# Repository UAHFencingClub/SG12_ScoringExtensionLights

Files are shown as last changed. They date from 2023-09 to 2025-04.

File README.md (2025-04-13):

# SG12_ScoringExtensionLights

A module for the [SG12 fencing scoring machine](https://www.blue-gauntlet.com/SG12-ST-MACHINE-w-score-and-time-and-remote_p_3799.html) that allows for 12V LED strips to be used as extension lights.

You can view the mirror on [CADLAB.io](https://cadlab.io/project/27194/main/files) if you want to see the schematic. < Needs to be updated, not sure why mirroring is not working.

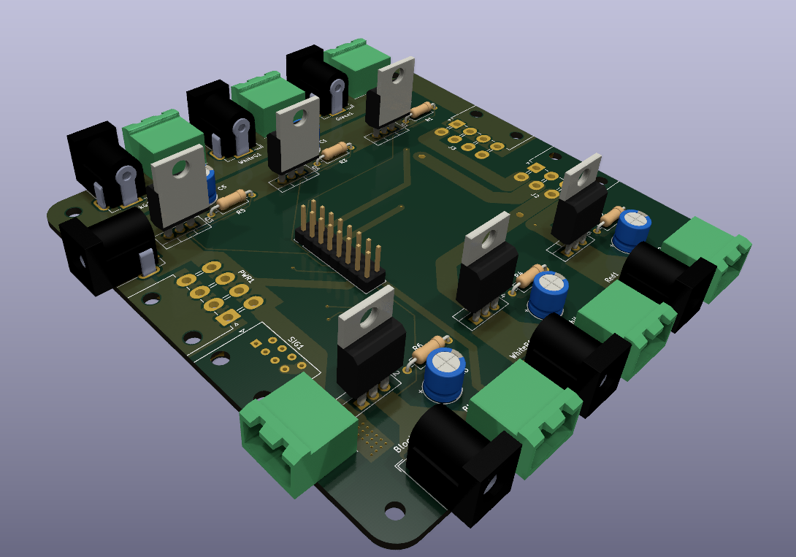
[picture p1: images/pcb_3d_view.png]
Image of 3D PCB Rendering


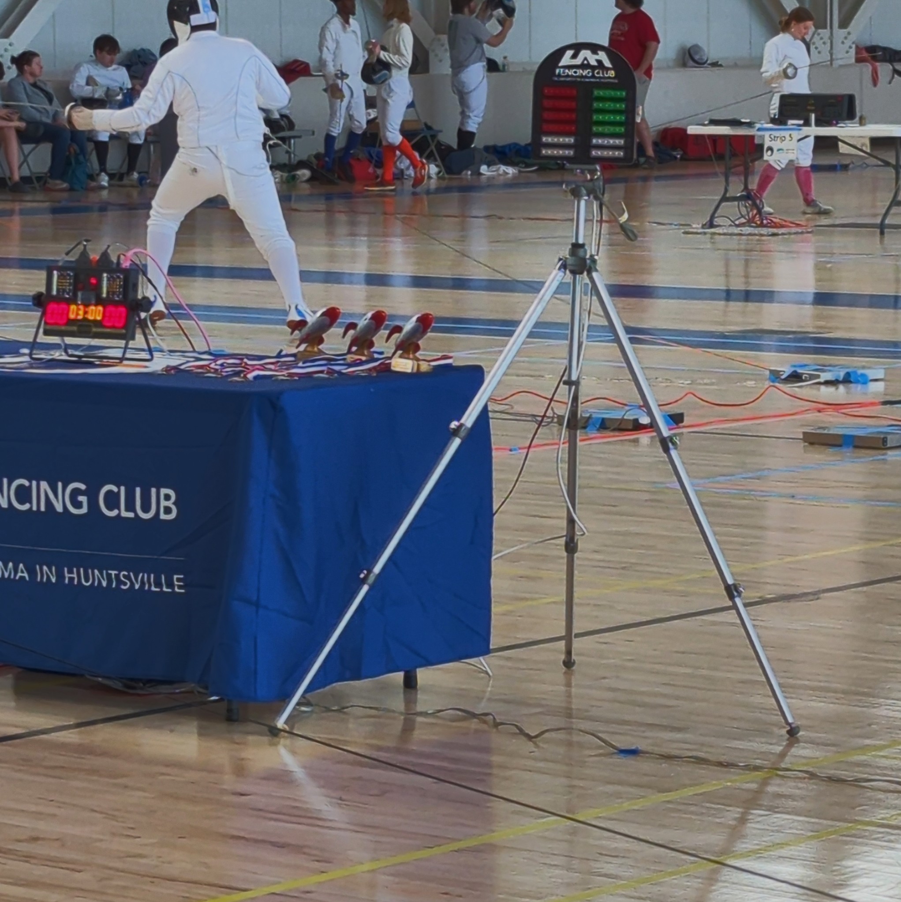
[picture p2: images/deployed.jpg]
Deployed Extension Lights


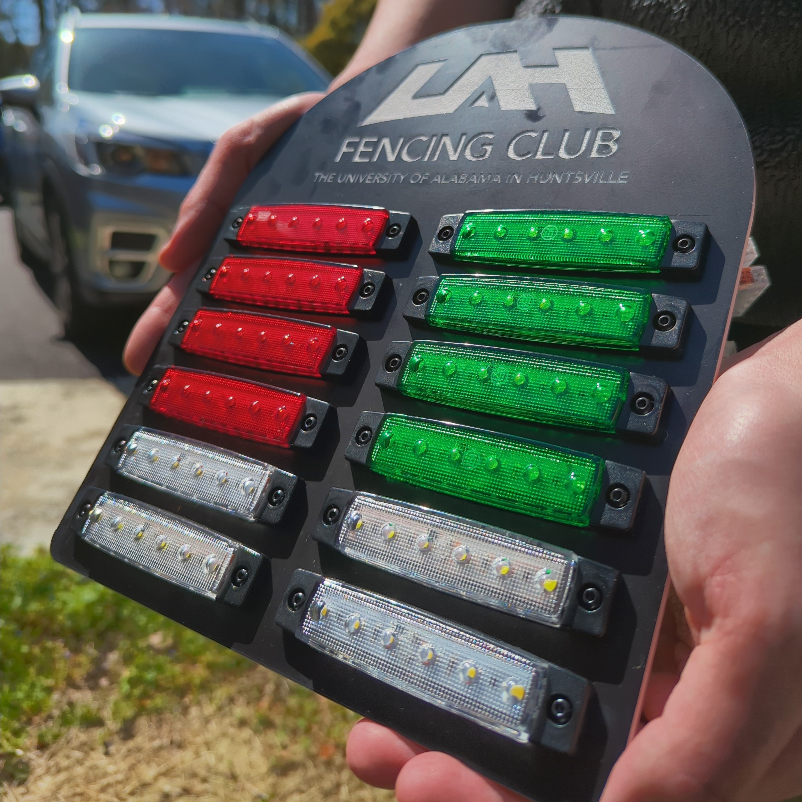
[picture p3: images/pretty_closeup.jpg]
Closeup


# Wiring Diagram

Annocations and a wiring diagram can be found [here](Wiring.md)

# Parts (Haphazard)

Most things I got off amazon. I have not gotten all the connectors since not all are actually required. It depends on what you need. Look at the schematic to find out.

- IRF4905 MOSFET (Though probably most P Channel MOSFETs will do)
- Some sort of RJ45 (Ethernet) Connector (Don't get the ones with built in magnetics, those are usually a bit larger and are only for actual ethernet applications.
- Whatever 10k resistors you can find, the value really does not matter I would suggest something between 1k and 100k
- Some sort of barrel jack connector (Inner pin diameter of 2.1mm is more common than ones with 2.5mm inner pin diameter)
- PhoenixContact MSTBA 2,5 2-G-5,08 1x02 P5.08mm Horizontal
- Molex Mini-Fit Jr 5569 2x04 P4.20mm Horizontal
- Standard 2.54mm pin header

# Get PCBs

**Disclaimer: If ordering through their site, PCBWay will "donate 10% PCB and PCB assembly cost to" [me](https://github.com/QuantumEF)**

<a href="https://www.pcbway.com/project/shareproject/SG12_ScoringExtensionLights_36ba9fa8.html">PCB from PCBWay</a>

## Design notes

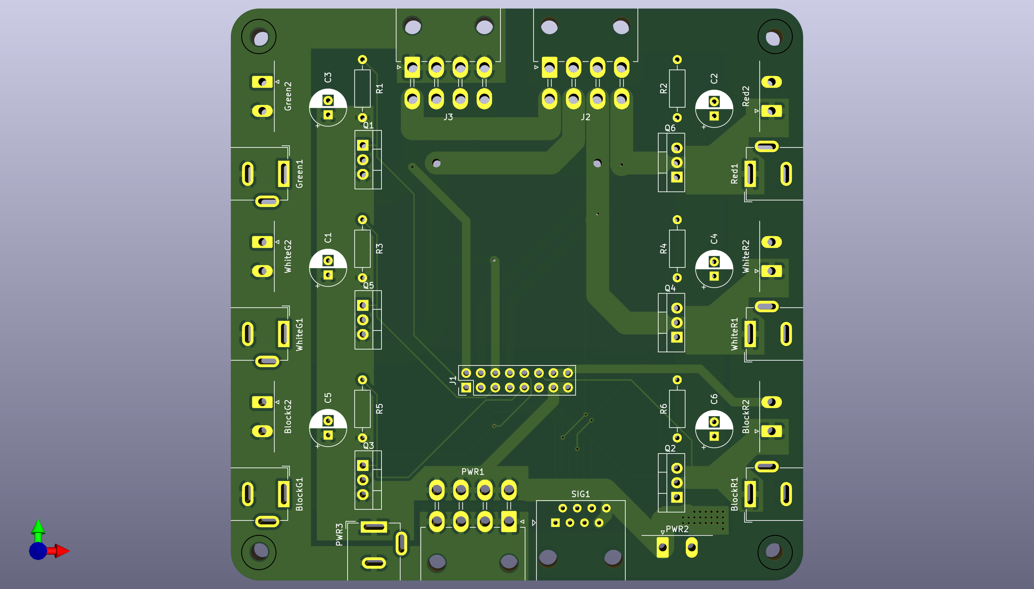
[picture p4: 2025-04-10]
images/pcb_3d_view_birdseye.png

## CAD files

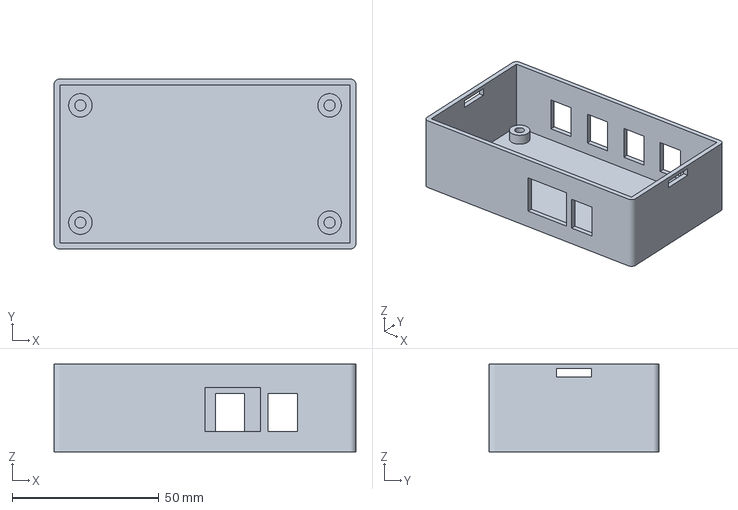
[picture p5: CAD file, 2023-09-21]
3dmodels/Case-CaseFull.3mf
103.0 x 58.0 x 30.0 mm

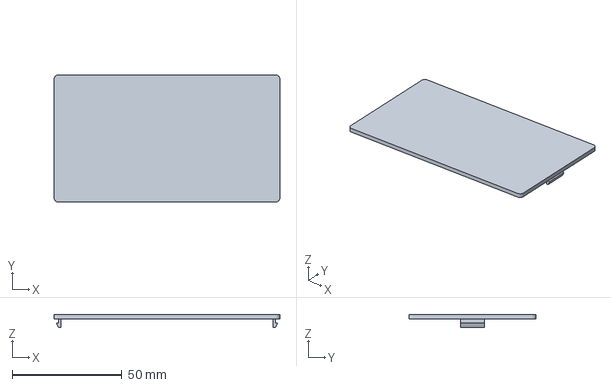
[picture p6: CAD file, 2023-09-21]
3dmodels/Case-LidFull.3mf
103.0 x 58.0 x 6.00 mm

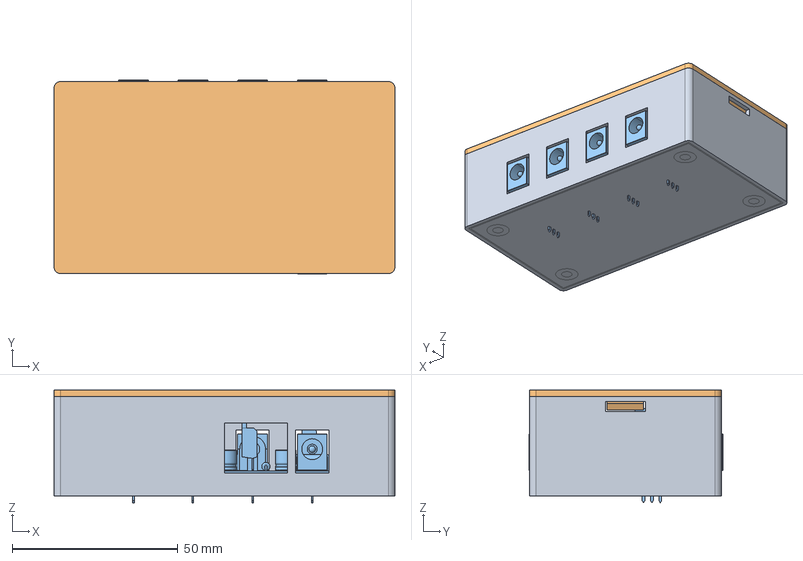
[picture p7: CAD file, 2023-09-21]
3dmodels/Case.FCStd
103.0 x 58.6 x 34.1 mm
CaseFull
LidFull
SG12_Scoring_Extension_Breakout

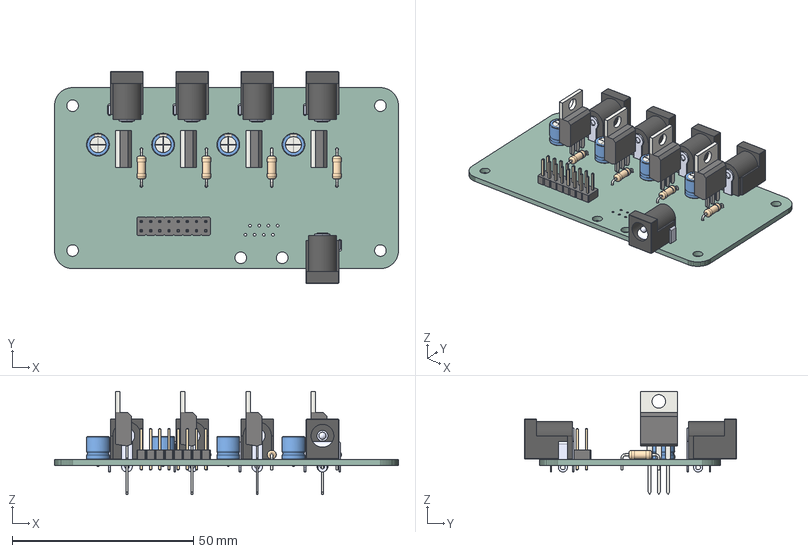
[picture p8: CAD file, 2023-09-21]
3dmodels/SG12_Scoring_Extension_Breakout.step
95.0 x 58.5 x 28.5 mm
SG12_Scoring_Extension_Breakout PCB

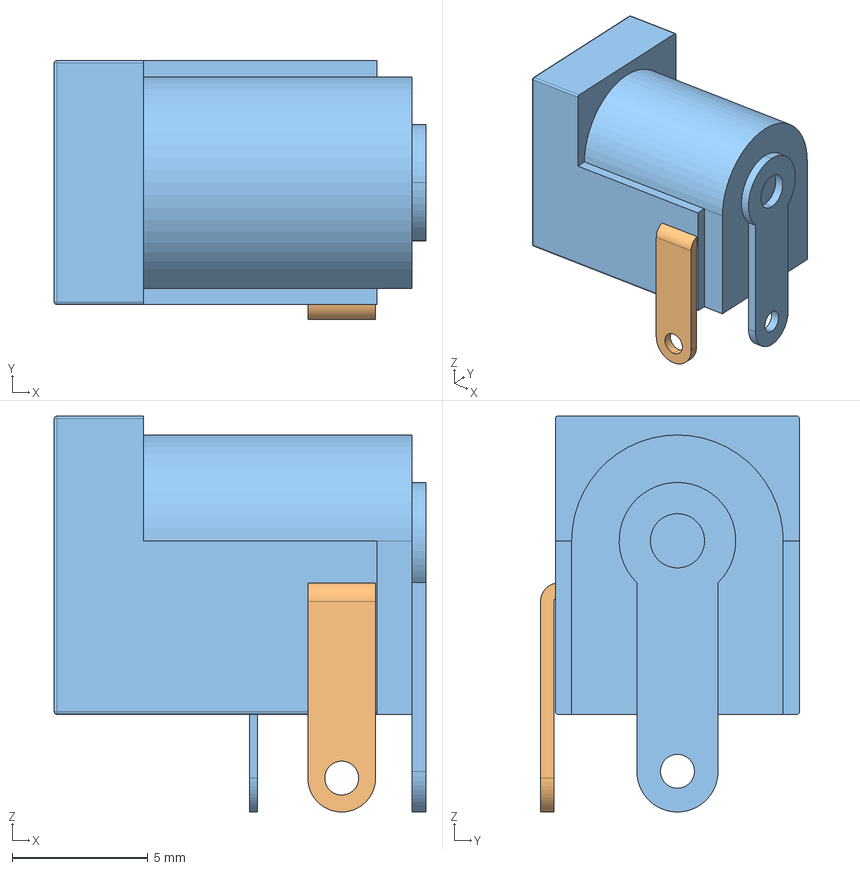
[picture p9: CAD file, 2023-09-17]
3dmodels/Sparkfun_BarrelJack_adaptation.FCStd
13.7 x 9.55 x 14.6 mm

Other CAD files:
3dmodels/Sparkfun_BarrelJack_119.STEP
3dmodels/Sparkfun_BarrelJack_119-adaptation.STEP
3dmodels/Case-CaseFull.stl
3dmodels/Case-LidFull.stl

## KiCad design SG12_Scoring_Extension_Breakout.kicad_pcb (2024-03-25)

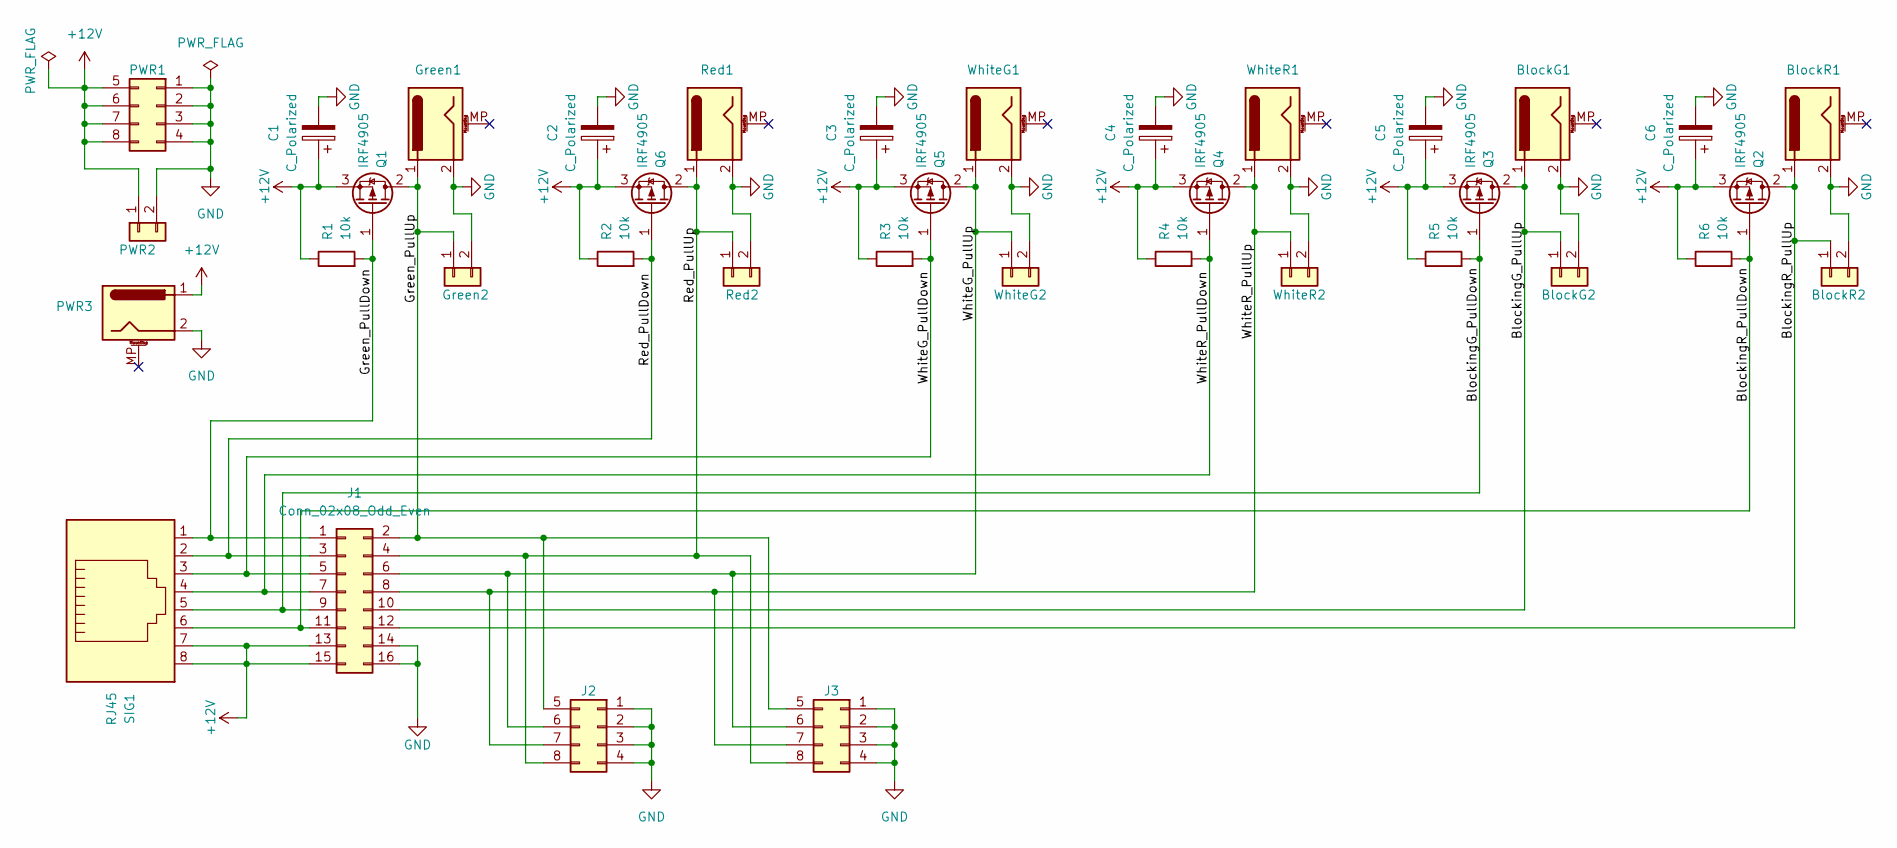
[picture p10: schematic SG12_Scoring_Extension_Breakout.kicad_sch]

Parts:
BlockG1: Barrel_Jack_MountingPin; BarrelJack_GCT_DCJ200-10-A_Horizontal
BlockG2: Conn_01x02; PhoenixContact_MSTBA_2,5_2-G-5,08_1x02_P5.08mm_Horizontal
BlockR1: Barrel_Jack_MountingPin; BarrelJack_GCT_DCJ200-10-A_Horizontal
BlockR2: Conn_01x02; PhoenixContact_MSTBA_2,5_2-G-5,08_1x02_P5.08mm_Horizontal
C1, C2, C3, C4, C5, C6: C_Polarized; CP_Radial_D6.3mm_P2.50mm
Green1: Barrel_Jack_MountingPin; BarrelJack_GCT_DCJ200-10-A_Horizontal
Green2: Conn_01x02; PhoenixContact_MSTBA_2,5_2-G-5,08_1x02_P5.08mm_Horizontal
J1: Conn_02x08_Odd_Even; PinHeader_2x08_P2.54mm_Vertical
J2, J3: Conn_02x04_Top_Bottom; Molex_Mini-Fit_Jr_5569-08A2_2x04_P4.20mm_Horizontal
PWR1: Conn_02x04_Top_Bottom; Molex_Mini-Fit_Jr_5569-08A2_2x04_P4.20mm_Horizontal
PWR2: Conn_01x02; PhoenixContact_MSTBA_2,5_2-G-5,08_1x02_P5.08mm_Horizontal
PWR3: Barrel_Jack_MountingPin; BarrelJack_GCT_DCJ200-10-A_Horizontal
Q1, Q2, Q3, Q4, Q5, Q6: IRF4905; TO-220-3_Vertical
R1, R2, R3, R4, R5, R6: 10k; R_Axial_DIN0207_L6.3mm_D2.5mm_P10.16mm_Horizontal
Red1: Barrel_Jack_MountingPin; BarrelJack_GCT_DCJ200-10-A_Horizontal
Red2: Conn_01x02; PhoenixContact_MSTBA_2,5_2-G-5,08_1x02_P5.08mm_Horizontal
SIG1: RJ45; RJ45_Amphenol_54602-x08_Horizontal
WhiteG1: Barrel_Jack_MountingPin; BarrelJack_GCT_DCJ200-10-A_Horizontal
WhiteG2: Conn_01x02; PhoenixContact_MSTBA_2,5_2-G-5,08_1x02_P5.08mm_Horizontal
WhiteR1: Barrel_Jack_MountingPin; BarrelJack_GCT_DCJ200-10-A_Horizontal
WhiteR2: Conn_01x02; PhoenixContact_MSTBA_2,5_2-G-5,08_1x02_P5.08mm_Horizontal

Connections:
+12V: C1.1, C2.1, C3.1, C4.1, C5.1, C6.1, J1.13, J1.15, PWR1.5, PWR1.6, PWR1.7, PWR1.8, PWR2.1, PWR3.1, Q1.3 (S), Q2.3 (S), Q3.3 (S), Q4.3 (S), Q5.3 (S), Q6.3 (S), R1.1, R2.1, R3.1, R4.1, R5.1, R6.1, SIG1.7, SIG1.8
/BlockingG_PullDown: J1.9, Q3.1 (G), R5.2, SIG1.5
/BlockingG_PullUp: BlockG1.1, BlockG2.1, J1.10, Q3.2 (D)
/BlockingR_PullDown: J1.11, Q2.1 (G), R6.2, SIG1.6
/BlockingR_PullUp: BlockR1.1, BlockR2.1, J1.12, Q2.2 (D)
/Green_PullDown: J1.1, Q1.1 (G), R1.2, SIG1.1
/Green_PullUp: Green1.1, Green2.1, J1.2, J2.5, J3.5, Q1.2 (D)
/Red_PullDown: J1.3, Q6.1 (G), R2.2, SIG1.2
/Red_PullUp: J1.4, J2.8, J3.8, Q6.2 (D), Red1.1, Red2.1
/WhiteG_PullDown: J1.5, Q5.1 (G), R3.2, SIG1.3
/WhiteG_PullUp: J1.6, J2.6, J3.6, Q5.2 (D), WhiteG1.1, WhiteG2.1
/WhiteR_PullDown: J1.7, Q4.1 (G), R4.2, SIG1.4
/WhiteR_PullUp: J1.8, J2.7, J3.7, Q4.2 (D), WhiteR1.1, WhiteR2.1
GND: BlockG1.2, BlockG2.2, BlockR1.2, BlockR2.2, C1.2, C2.2, C3.2, C4.2, C5.2, C6.2, Green1.2, Green2.2, J1.14, J1.16, J2.1, J2.2, J2.3, J2.4, J3.1, J3.2, J3.3, J3.4, PWR1.1, PWR1.2, PWR1.3, PWR1.4, PWR2.2, PWR3.2, Red1.2, Red2.2, WhiteG1.2, WhiteG2.2, WhiteR1.2, WhiteR2.2

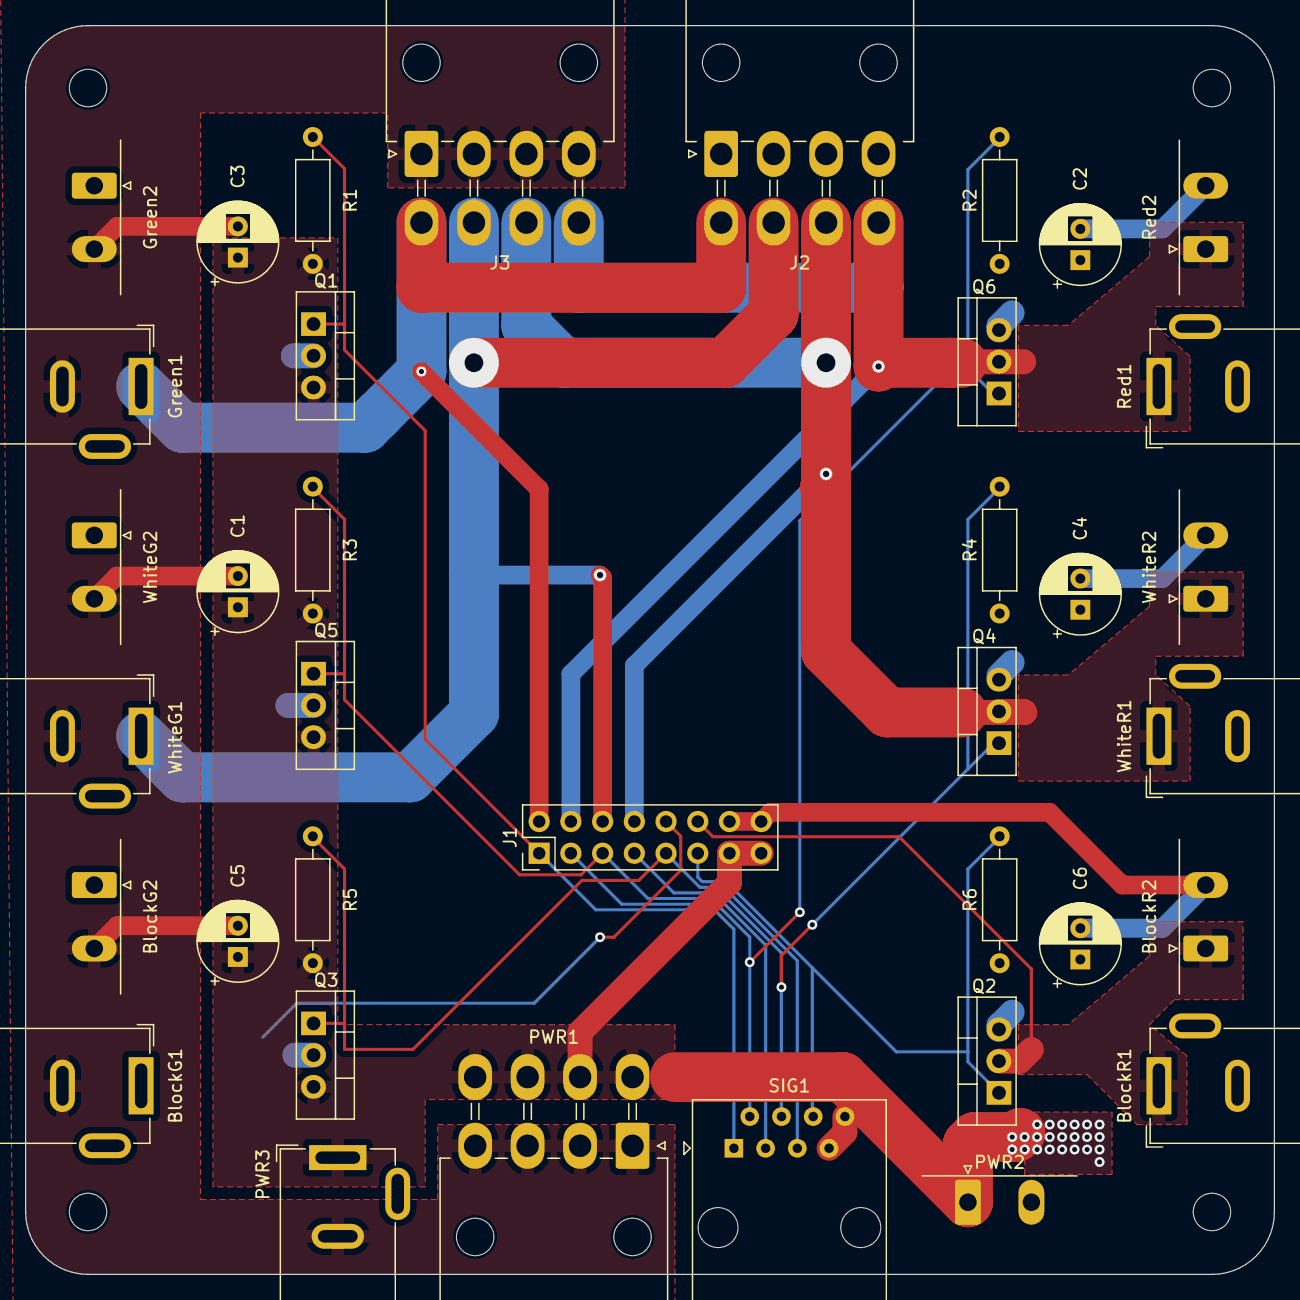
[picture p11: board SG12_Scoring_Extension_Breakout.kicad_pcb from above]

Board: 2 copper layers, 100.0 x 100.0 mm, 37 parts (0 on the bottom side), 14 nets.

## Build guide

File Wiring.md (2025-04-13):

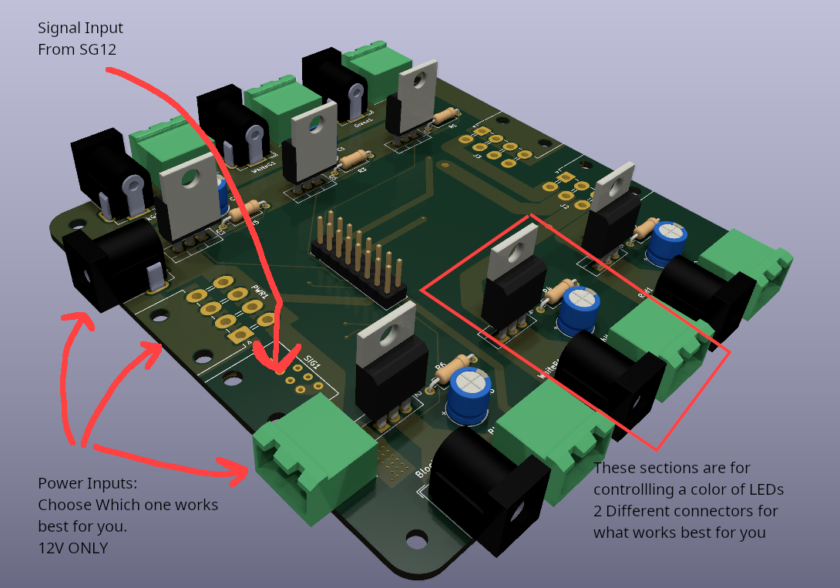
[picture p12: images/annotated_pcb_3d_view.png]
Annotated Image of 3D PCB Rendering

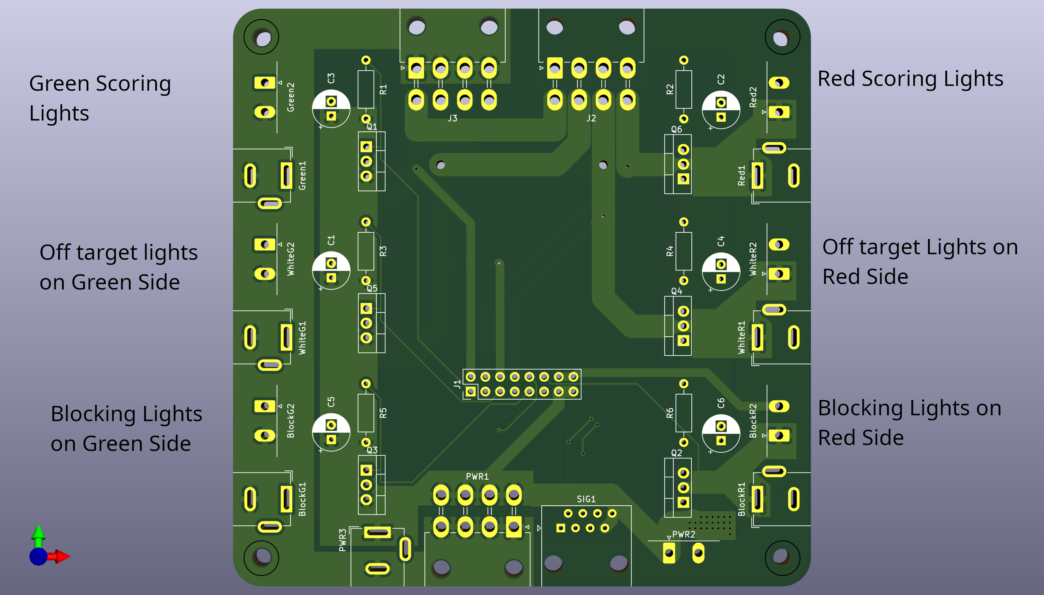
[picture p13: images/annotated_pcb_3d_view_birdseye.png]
Annotated image of a birdseye view

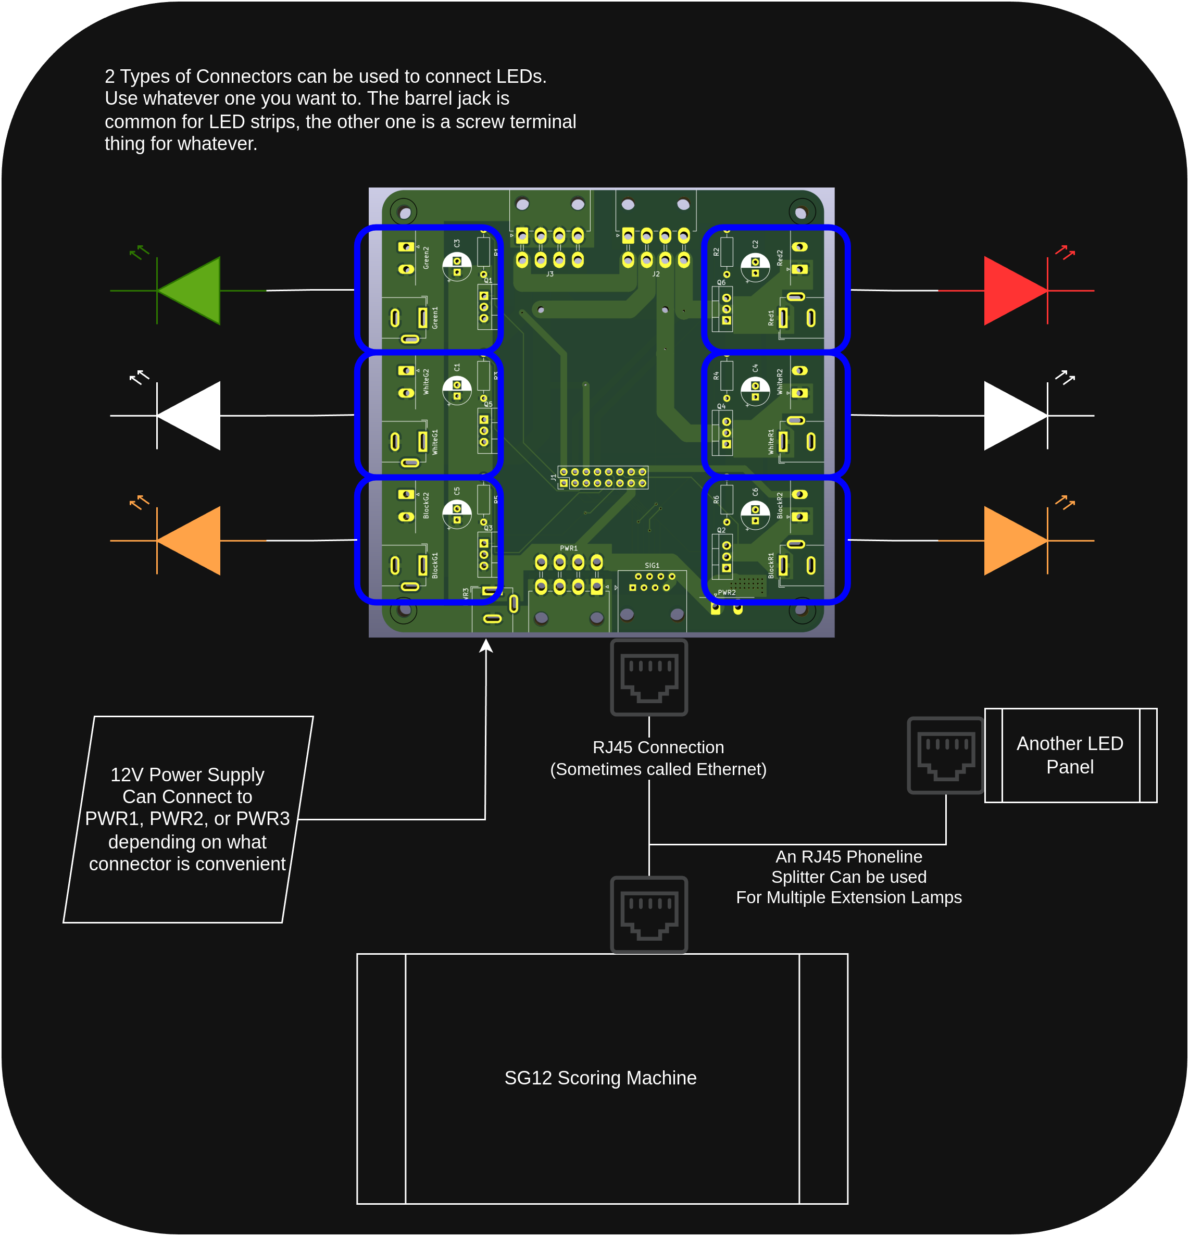
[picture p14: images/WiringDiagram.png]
Wiring Diagram

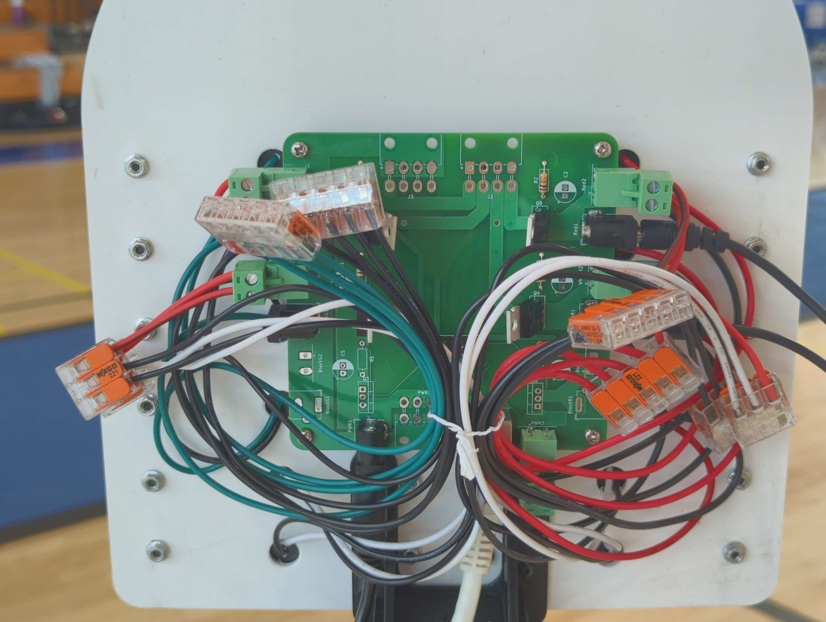
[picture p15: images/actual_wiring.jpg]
Actual Wiring Picture


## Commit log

2023-09-07 Update to newer kicad version
    [fencing_sg12_lights.kicad_sch]
2023-09-15 Updated and redid from scratch
    [SG12_Scoring_Extension_Breakout.kicad_pcb, SG12_Scoring_Extension_Breakout.kicad_sch]
2023-09-15 Removed old files and added gitignore
    [fencing_sg12_lights.kicad_sch, fencing_sg12_lights.sch]
2023-09-15 Messed up a footprint
    [SG12_Scoring_Extension_Breakout.kicad_sch]
2023-09-15 WIP: PCB Layout, Items placed
    [SG12_Scoring_Extension_Breakout.kicad_pcb]
2023-09-15 Some Initial PCB traces, will redo since I am not happy, and the scematic may be wrong
    [SG12_Scoring_Extension_Breakout.kicad_pcb]
2023-09-15 Added decoupling capacitors and extra header
    [SG12_Scoring_Extension_Breakout.kicad_sch]
2023-09-16 Added footprints
    [SG12_Scoring_Extension_Breakout.kicad_sch]
2023-09-16 Some Initial PCB Layout
    [SG12_Scoring_Extension_Breakout.kicad_pcb]
2023-09-16 Finished up initial routing, need to check rules
    [SG12_Scoring_Extension_Breakout.kicad_pcb, SG12_Scoring_Extension_Breakout.kicad_sch]
2023-09-16 Removed off-board silkscreen
    [SG12_Scoring_Extension_Breakout.kicad_pcb]
2023-09-16 Added silkscreen text
    [SG12_Scoring_Extension_Breakout.kicad_pcb]
2023-09-16 More silkscreen
    [SG12_Scoring_Extension_Breakout.kicad_pcb]
2023-09-16 Updated routing and RJ45 footprint
    [SG12_Scoring_Extension_Breakout.kicad_pcb, SG12_Scoring_Extension_Breakout.kicad_sch]
2023-09-16 Added liscense to silk screen
    [SG12_Scoring_Extension_Breakout.kicad_pcb]
2023-09-17 Minor routing adjustments
    [SG12_Scoring_Extension_Breakout.kicad_pcb]
2023-09-17 More trace finetuning because I am bored
    [SG12_Scoring_Extension_Breakout.kicad_pcb]
2023-09-17 Added more overhang for connectors
    [SG12_Scoring_Extension_Breakout.kicad_pcb]
2023-09-17 Forgot to move labels
    [SG12_Scoring_Extension_Breakout.kicad_pcb]
2023-09-17 Added 3d models for barrel jacks
    [SG12_Scoring_Extension_Breakout.kicad_pcb, SG12_Scoring_Extension_Breakout.kicad_sch, Sparkfun_BarrelJack_119-adaptation.STEP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]
2023-09-17 Export of initial 3d model
    [SG12_Scoring_Extension_Breakout.step]
2023-09-18 Case Design
    [Case-CaseFull.stl, Case-LidFull.stl, Case.FCStd]
2023-09-18 Updated case lid
    [Case-LidFull.stl]
2023-09-19 Updated lid design, forgot to push freecad model
    [Case.FCStd]
2023-09-21 updated pcb dimensions and silkscreen
    [SG12_Scoring_Extension_Breakout.kicad_pcb]
2023-09-21 various updates
    [SG12_Scoring_Extension_Breakout.kicad_pcb]
2023-09-21 Updated 3d model
    [SG12_Scoring_Extension_Breakout.step]
2023-09-21 Updated case
    [Case-CaseFull.3mf, Case-LidFull.3mf, Case.FCStd]
2023-09-26 updated some silkscreen and trace widths
    [SG12_Scoring_Extension_Breakout.kicad_pcb]
2023-10-06 Updated schematic with extra connections
    [SG12_Scoring_Extension_Breakout.kicad_pcb, SG12_Scoring_Extension_Breakout.kicad_sch]
2023-10-06 Forgot connector
    [SG12_Scoring_Extension_Breakout.kicad_sch]
2023-10-06 Rough component placement
    [SG12_Scoring_Extension_Breakout.kicad_pcb]
2023-10-06 Added mouting holes, iteration 2
    [SG12_Scoring_Extension_Breakout.kicad_pcb]
2023-10-06 Flipped connections on mini-fit connectors to match EPS12V
    [SG12_Scoring_Extension_Breakout.kicad_pcb, SG12_Scoring_Extension_Breakout.kicad_sch]
2023-10-06 Very nitpicky positioning on the Red and Green connectors
    [SG12_Scoring_Extension_Breakout.kicad_pcb]
2023-10-06 Very nitpicky mofet and resistor placement
    [SG12_Scoring_Extension_Breakout.kicad_pcb]
2023-10-06 Initial footprint placement
    [SG12_Scoring_Extension_Breakout.kicad_pcb]
2023-10-06 Switched connections for easier routing later
    [SG12_Scoring_Extension_Breakout.kicad_sch]
2023-10-06 Switched more connections for easier routing later
    [SG12_Scoring_Extension_Breakout.kicad_sch]
2023-10-06 Some initial routing
    [SG12_Scoring_Extension_Breakout.kicad_pcb]
2023-10-11 Finished routing
    [SG12_Scoring_Extension_Breakout.kicad_pcb]
2023-10-11 Routing adjustments
    [SG12_Scoring_Extension_Breakout.kicad_pcb]
2023-10-11 Schematic Symbol Names
    [SG12_Scoring_Extension_Breakout.kicad_sch]
2023-10-11 Silkscreen Labels
    [SG12_Scoring_Extension_Breakout.kicad_pcb]
2023-10-11 Ignoring sinkscreen clippings
    [SG12_Scoring_Extension_Breakout.kicad_pcb]
2023-10-11 Re-added thermal reliefs
    [SG12_Scoring_Extension_Breakout.kicad_pcb]
2023-10-11 Updated some via sizes
    [SG12_Scoring_Extension_Breakout.kicad_pcb]
2023-10-11 Power flags for ERC checker
    [SG12_Scoring_Extension_Breakout.kicad_sch]
2023-10-12 Footprint modifications
    [SG12_Scoring_Extension_Breakout.kicad_pcb, SG12_Scoring_Extension_Breakout.kicad_sch]
2023-10-13 moved power vias
    [SG12_Scoring_Extension_Breakout.kicad_pcb]
2024-03-25 first manufactured board
    [SG12_Scoring_Extension_Breakout.kicad_pcb, SG12_Scoring_Extension_Breakout.kicad_sch]
2024-03-30 Update README.md with PCBWay
2025-04-10 Initial WiringDiagrams
2025-04-10 Wiring Diagram updates and documentation
2025-04-10 Minor Fix for Wiring diagrams
